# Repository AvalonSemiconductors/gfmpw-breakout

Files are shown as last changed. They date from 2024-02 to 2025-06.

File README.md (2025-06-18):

# gfmpw-breakout
This repo contains all the files, including production-ready gerber files, for this PCB:

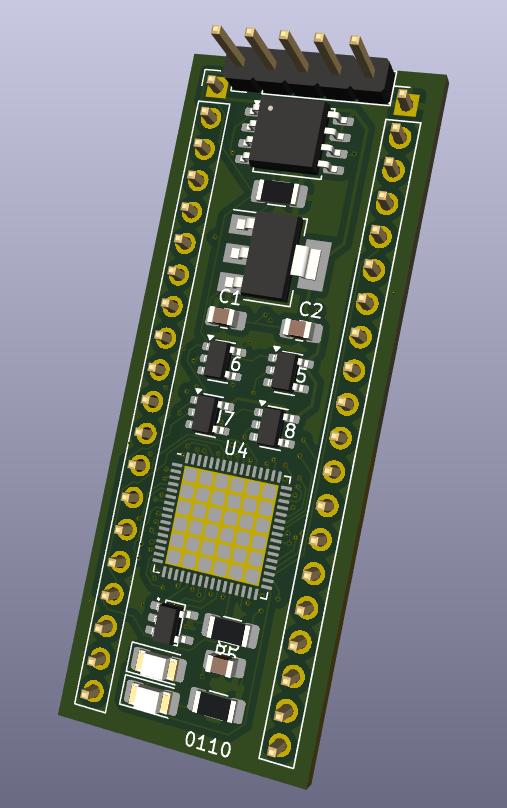
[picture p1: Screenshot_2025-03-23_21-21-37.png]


It contains all components on-board to keep the caravel management controller happy and breaks out the user IO lines into the same footprint as a DIP-40 IC. The board is meant for both prototyping, i.e. on a breadboard, or use as a module on another PCB.

Specifically, it has:

 - Space for any GFMPW IC
 - Spiflash IC for mangement controller firmware, plus required level shifters and 3.3V voltage regulator
 - Programming header for SPI flash
 - Power-on reset circuitry
 - LED on ``gpio``
 - Breakouts for pins ``mprj_io[37:5]`` as well as ``mprj_io[0]``, ``mprj_io[1]`` and ``mprj_io[4]``

Note: the board does not have the capability to program the 25Q32 spiflash in-place. To program it, any number of portable ROM programmers can be used, such as the [CH341A](https://www.amazon.com/Programmer-Module-CH341A-Burner-5V-3-3V/dp/B07PFCJ8G9) (I recommend this device as it is supported by the `flashrom` utility on most Linux distros) and wire the programming header to it.

The pinout of the board is as such (a KiCad symbol is [also available](board_symbol.kicad_sym)):

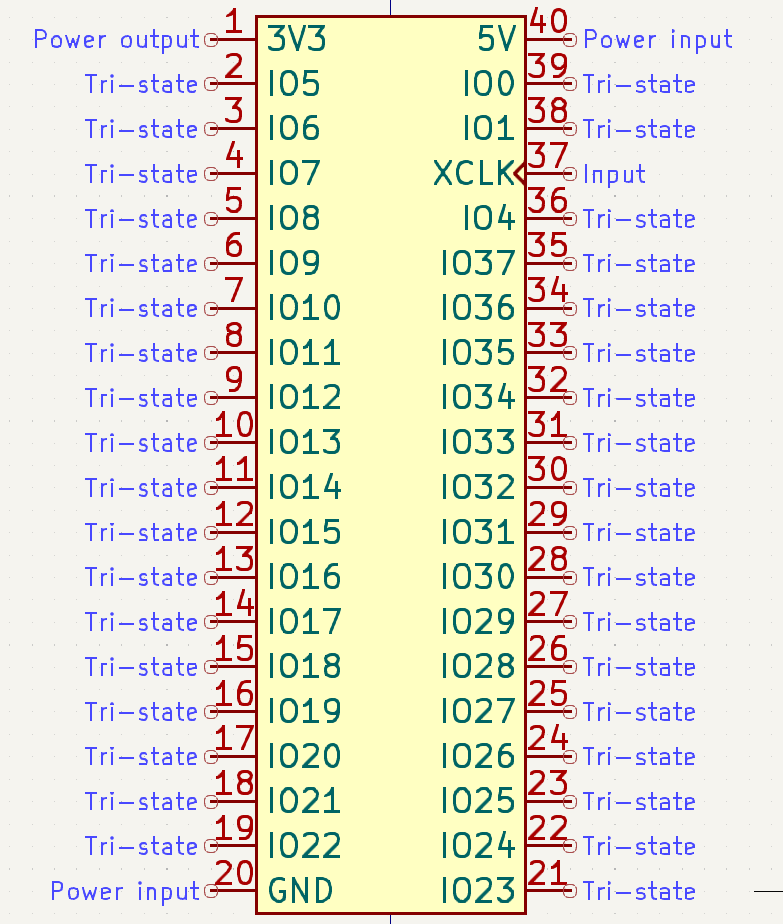
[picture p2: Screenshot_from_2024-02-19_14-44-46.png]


Note that 3V3 is a output from the on-board voltage regulator. The only power input is 5V.

To edit the KiCad files, you will need to add the ``Caravel_Board.pretty`` footprint files from the efabless/caravel_board repo, which can be obtained [here](https://github.com/efabless/caravel_board/tree/main/hardware/footprints/Caravel_Board.pretty).

# BOM

| Designator(s) | Value | TME # | Mouser # |
|---|---|---|---|
| U1 | AMS1117-3.3 | AZ1117H-3.3TRE1 | 595-REG1117-3.3 |
| U2 | 25Q32 or compatible | MX25L1006EMI-10G | 454-W25Q32JVSSIMTR |
| U3 | MCP1319MT | MCP1319MT-29LT | 579-MCP1319MT29LE/OT |
| U4 | GFMPW IC | N/A | N/A |
| U5, U6, U7, U8 | SN74LV1T126 | - |  595-74LV1T126QDBVRQ1 |
| D1, D2 | LED 1206 (metric 3216) | 24-21SURC/S530-A2 | 630-HSMH-H150 |
| R4, R5, R6 | 1K 1206 (metric 3216) | 1206S4F1001T5E | 71-RCA12061K00JNEA |
| C1, C2, C3 | 1µF 0805 (metric 2012) | 08053C105J4T2A | 810-CGA4J3X7R1H105MS |

Assembled board should look like this:

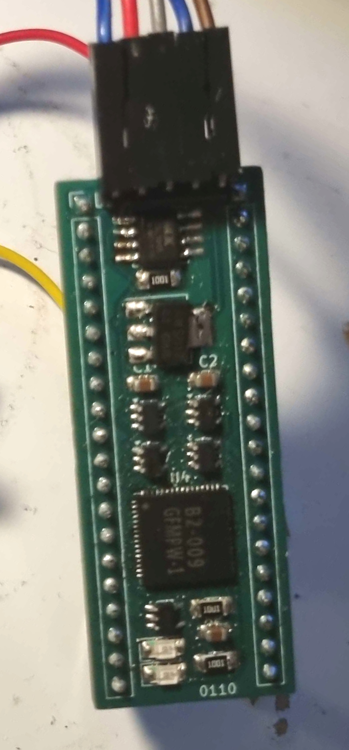
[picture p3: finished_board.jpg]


After building, the programmer hookup (CH341A) is like follows. This may even work for in-system programming, but the programmer powers the board, so its intended to be a standalone setup.
Note that connecting the programmer holds caravel in reset until the physical connections to the programmer are disconnected.

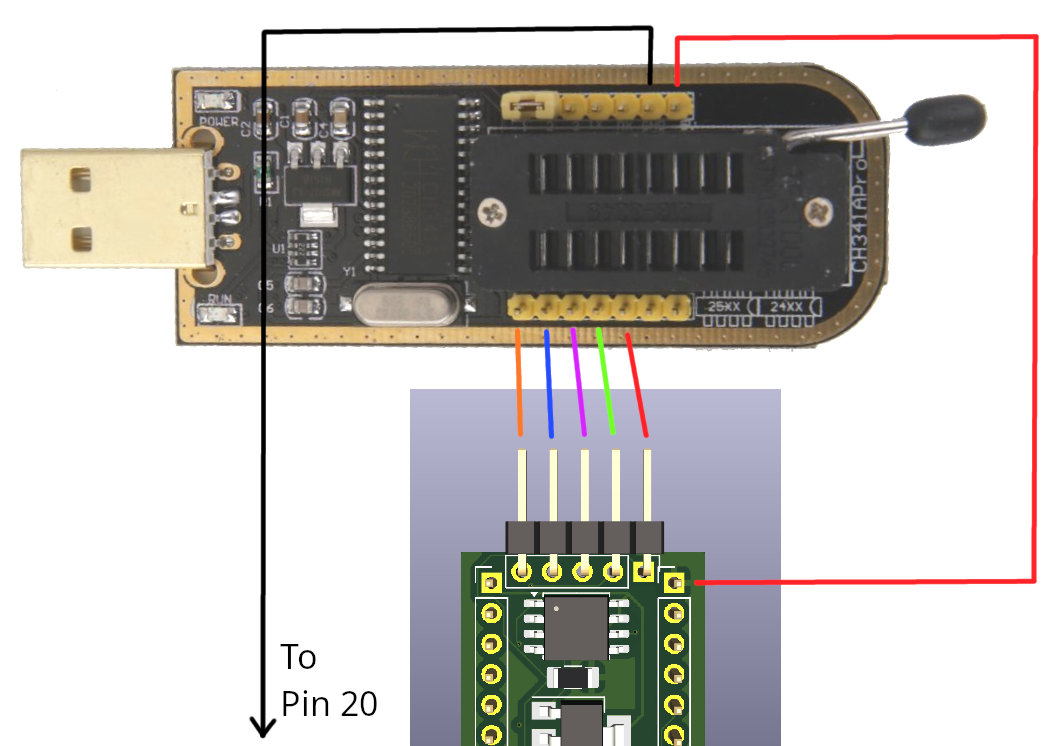
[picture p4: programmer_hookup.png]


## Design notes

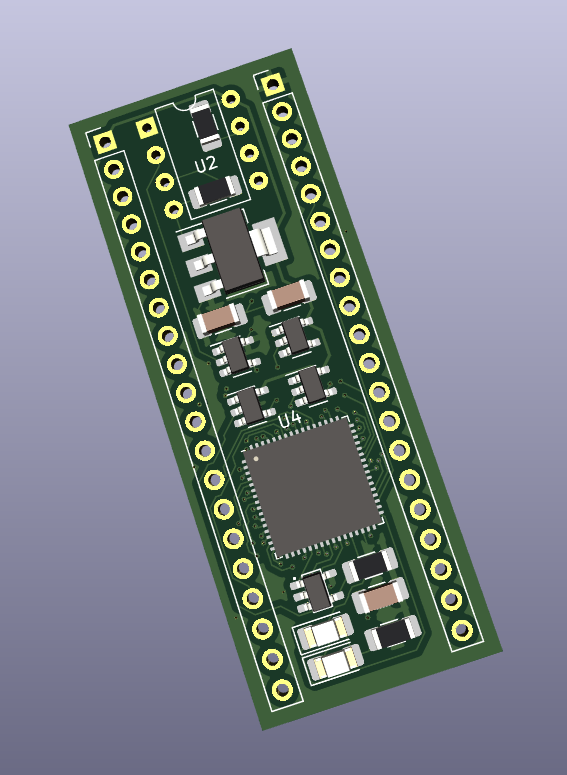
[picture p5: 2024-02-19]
Screenshot_2024-01-27_17-30-15.png

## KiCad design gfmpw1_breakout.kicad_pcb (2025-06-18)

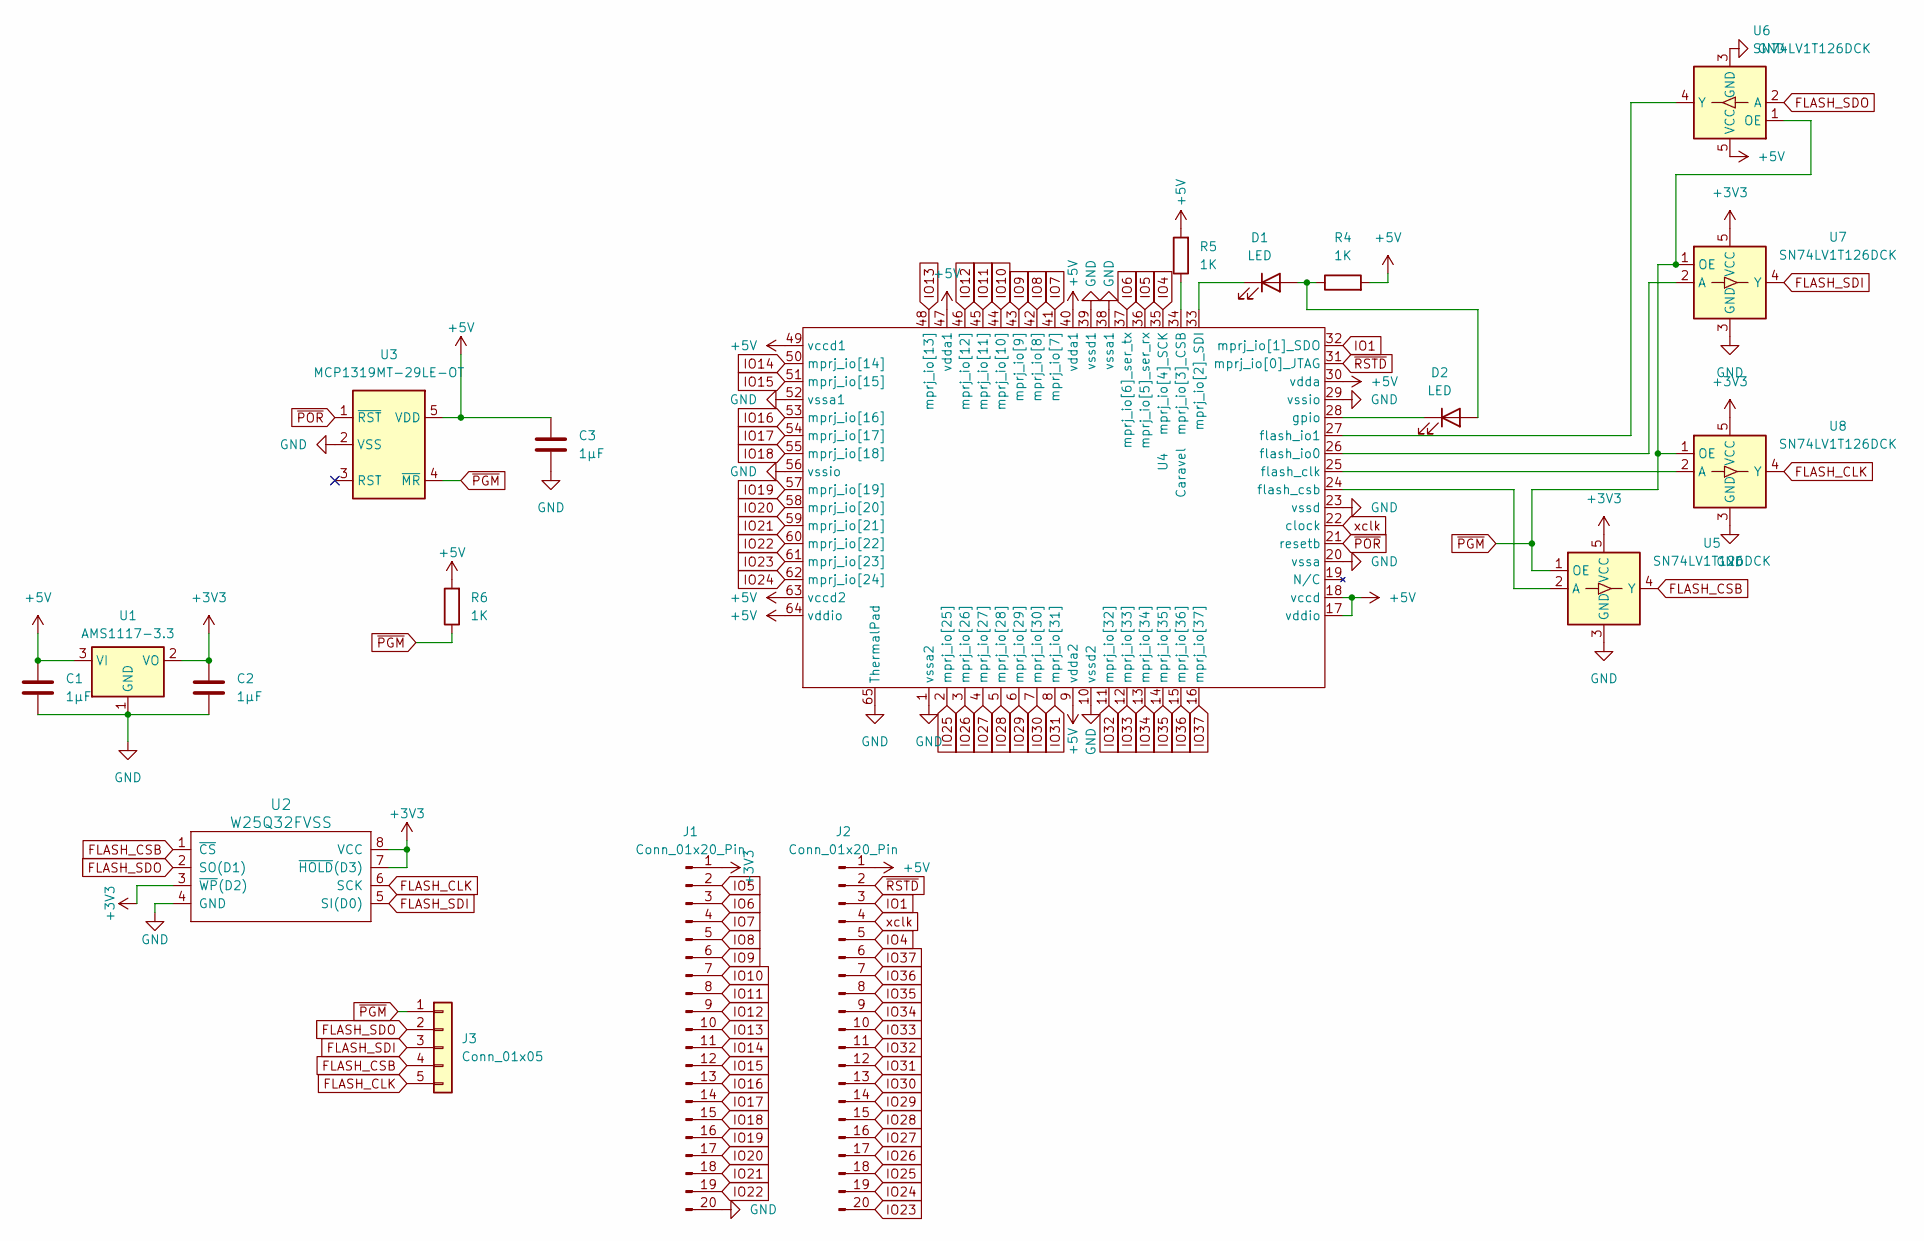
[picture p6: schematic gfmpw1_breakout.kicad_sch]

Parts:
C1, C2, C3: 1µF; C_0805_2012Metric_Pad1.18x1.45mm_HandSolder
D1, D2: LED; LED_1206_3216Metric_Pad1.42x1.75mm_HandSolder
J1, J2: Conn_01x20_Pin; PinHeader_1x20_P2.54mm_Vertical
J3: Conn_01x05; PinHeader_1x05_P2.54mm_Vertical
R4, R5, R6: 1K; R_1206_3216Metric_Pad1.30x1.75mm_HandSolder
U1: AMS1117-3.3; SOT-223-3_TabPin2
U2: W25Q32FVSS; SOIC-8_5.3x5.3mm_P1.27mm
U3: MCP1319MT-29LE-OT; PoR_5_SOT23
U4: Caravel; QFN-64-1EP_9x9mm_P0.5mm_EP7.65x7.65mm
U5, U6, U7, U8: SN74LV1T126DCK; SOT-23-5

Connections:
+3V3: C2.1, J1.1, U1.2 (VO), U2.3 (~WP(D2)), U2.7 (~HOLD(D3)), U2.8 (VCC), U5.5 (VCC), U7.5 (VCC), U8.5 (VCC)
+5V: C1.1, C3.2, J2.1, R4.2, R5.2, R6.2, U1.3 (VI), U3.5 (VDD), U4.9 (vdda2), U4.17 (vddio), U4.18 (vccd), U4.30 (vdda), U4.40 (vdda1), U4.47 (vdda1), U4.49 (vccd1), U4.63 (vccd2), U4.64 (vddio), U6.5 (VCC)
FLASH_CLK: J3.5, U2.6 (SCK), U8.4 (Y)
FLASH_CSB: J3.4, U2.1 (~CS), U5.4 (Y)
FLASH_SDI: J3.3, U2.5 (SI(D0)), U7.4 (Y)
FLASH_SDO: J3.2, U2.2 (SO(D1)), U6.2 (A)
GND: C1.2, C2.2, C3.1, J1.20, U1.1 (GND), U2.4 (GND), U3.2 (VSS), U4.1 (vssa2), U4.10 (vssd2), U4.20 (vssa), U4.23 (vssd), U4.29 (vssio), U4.38 (vssa1), U4.39 (vssd1), U4.52 (vssa1), U4.56 (vssio), U4.65 (ThermalPad), U5.3 (GND), U6.3 (GND), U7.3 (GND), U8.3 (GND)
IO1: J2.3, U4.32 (mprj_io[1]_SDO)
IO4: J2.5, U4.35 (mprj_io[4]_SCK)
IO5: J1.2, U4.36 (mprj_io[5]_ser_rx)
IO6: J1.3, U4.37 (mprj_io[6]_ser_tx)
IO7: J1.4, U4.41 (mprj_io[7])
IO8: J1.5, U4.42 (mprj_io[8])
IO9: J1.6, U4.43 (mprj_io[9])
IO10: J1.7, U4.44 (mprj_io[10])
IO11: J1.8, U4.45 (mprj_io[11])
IO12: J1.9, U4.46 (mprj_io[12])
IO13: J1.10, U4.48 (mprj_io[13])
IO14: J1.11, U4.50 (mprj_io[14])
IO15: J1.12, U4.51 (mprj_io[15])
IO16: J1.13, U4.53 (mprj_io[16])
IO17: J1.14, U4.54 (mprj_io[17])
IO18: J1.15, U4.55 (mprj_io[18])
IO19: J1.16, U4.57 (mprj_io[19])
IO20: J1.17, U4.58 (mprj_io[20])
IO21: J1.18, U4.59 (mprj_io[21])
IO22: J1.19, U4.60 (mprj_io[22])
IO23: J2.20, U4.61 (mprj_io[23])
IO24: J2.19, U4.62 (mprj_io[24])
IO25: J2.18, U4.2 (mprj_io[25])
IO26: J2.17, U4.3 (mprj_io[26])
IO27: J2.16, U4.4 (mprj_io[27])
IO28: J2.15, U4.5 (mprj_io[28])
IO29: J2.14, U4.6 (mprj_io[29])
IO30: J2.13, U4.7 (mprj_io[30])
IO31: J2.12, U4.8 (mprj_io[31])
IO32: J2.11, U4.11 (mprj_io[32])
IO33: J2.10, U4.12 (mprj_io[33])
IO34: J2.9, U4.13 (mprj_io[34])
IO35: J2.8, U4.14 (mprj_io[35])
IO36: J2.7, U4.15 (mprj_io[36])
IO37: J2.6, U4.16 (mprj_io[37])
unnamed: D1.2 (A), D2.2 (A), R4.1
unnamed: D1.1 (K), U4.33 (mprj_io[2]_SDI)
unnamed: D2.1 (K), U4.28 (gpio)
unnamed: U4.25 (flash_clk), U8.2 (A)
unnamed: U4.24 (flash_csb), U5.2 (A)
unnamed: U4.26 (flash_io0), U7.2 (A)
unnamed: U4.27 (flash_io1), U6.4 (Y)
unnamed: R5.1, U4.34 (mprj_io[3]_CSB)
xclk: J2.4, U4.22 (clock)
~PGM: J3.1, R6.1, U3.4 (~MR), U5.1 (OE), U6.1 (OE), U7.1 (OE), U8.1 (OE)
~POR: U3.1 (~RST), U4.21 (resetb)
~RSTD: J2.2, U4.31 (mprj_io[0]_JTAG)

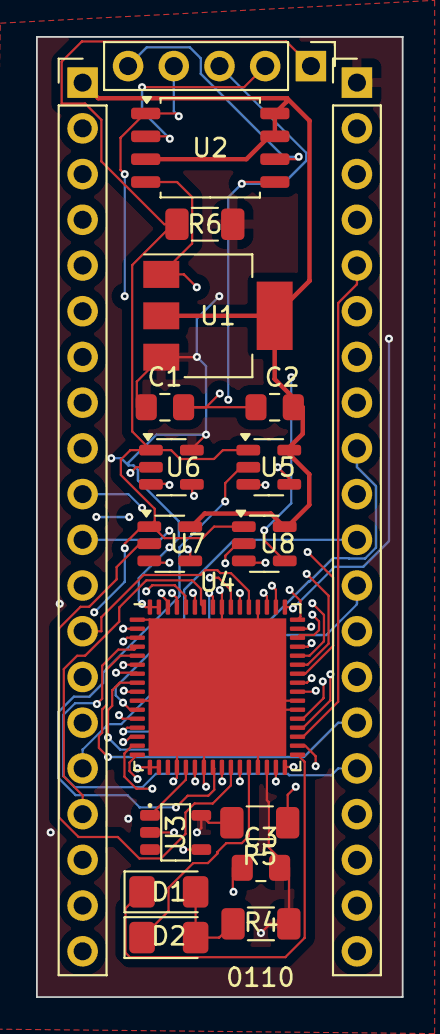
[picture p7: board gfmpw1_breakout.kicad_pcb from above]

Board: 4 copper layers, 20.3 x 53.3 mm, 19 parts (0 on the bottom side), 54 nets.

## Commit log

2024-02-19 KiCad symbol file
2024-02-19 The rest of the files.
    [gfmpw1_breakout.kicad_pcb, gfmpw1_breakout.kicad_sch]
2025-03-23 Revision 2
    [gfmpw1_breakout.kicad_pcb, gfmpw1_breakout.kicad_sch]
2025-06-18 Documentation updates & minor PCB file fix.
    [gfmpw1_breakout.kicad_pcb]
